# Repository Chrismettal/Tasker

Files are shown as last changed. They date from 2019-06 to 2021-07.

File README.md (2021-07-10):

Tasker_v0.3 Logo

# MOVING TO GITLAB

This project has been moved to Gitlab and will NOT be updated here anymore!

https://gitlab.com/Chrismettal/Tasker

Reworked version of Reminder with Google Calendar providing the same functionality as the original design, but providing an etched PCB making the build much cleaner and easier while providing a bit more documentation.
The PCB mostly uses SMD parts and includes everything to enable USB-upload just like a Wemos D1 mini for example.

Please check out Andreas' video of his original design:
https://www.youtube.com/watch?v=sm1-l5-z3ag

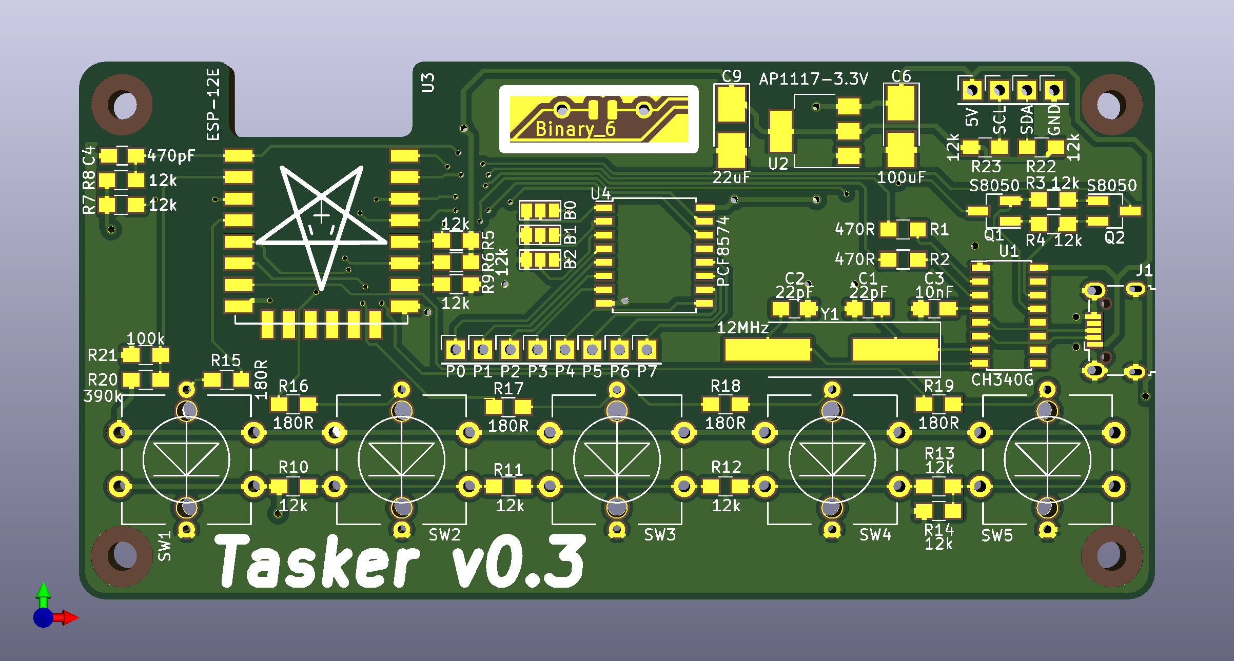
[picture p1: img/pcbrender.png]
Tasker_v0.3 PCB


Based on the original analog version to use 5 Buttons and 5 LEDs with available GPIO.

A PCF8574 port expander is routed over i2c on the PCB but currently not implemented in source code. Does not need to be placed for the rest to function. Could be implemented for further external triggers to set/reset automated functions.

# Buying

The PCB is now stocked on my Tindie store!



# Build Notes

Upload the gerber files made to your favourite PCB shop (or write me, i have spares).
The micro usb footprint is the "Wuerth Micro-B #629105150521" type, but a lot of chinese noname ones fit. If you can't get "the real thing" just look for a pack of various sizes. Some will fit.
__Flux it up!__
Start by placing the usb jack first as the CH340G will block your access a bit should you mess up the fine pins of the jack. Then place all the resistors, capacitos, transistors, then the bigger ICs and the crystal.
Only after all SMD parts are placed put in the buttons.

__Double check LED, C6 and C9 polarity!__

- C6 and C9 are tantalum caps that explode violently when you get their polarity wrong. The stripe (positive) should point to the C6/C9 writing on the PCB.
- R22 and R23 are optional I2C pullups, should you use something like an LCD over the I2C bus.
- Should you plan to upload code to the ESP before placing it, you could leave out U1, Q1, Q2, C1, C2, R1, R2, R3, R4, Y1.
- It does not matter if you power the device via USB or directly wire in 5 V to the pin header.
- U4 is optional. Should you place it you also have to place R22 and R23 and set an adress via B0, B1, B2.
- P0 - P7 are the in/outputs of U4.
- That cheap, chinese Arduino clone in your drawer is a good source for the CH340G that you forgot to order.
- You could also just order the bigger version of a NodeMCU and steal the ESP, AMS1117-3.3 ,CH340G and S8050s from that if you own a hot air rework station.
- If you are unhappy with the brightness of the LEDs you could change the values of R15 - R19. 

# Case

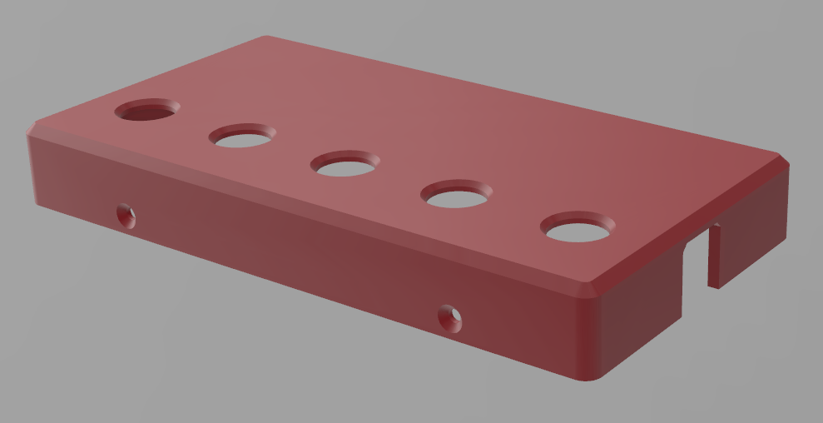
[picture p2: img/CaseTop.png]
CaseTop

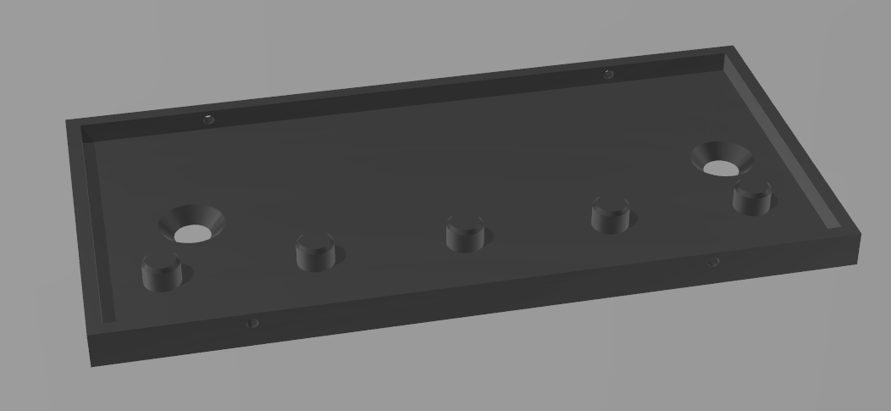
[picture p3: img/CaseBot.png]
CaseBot

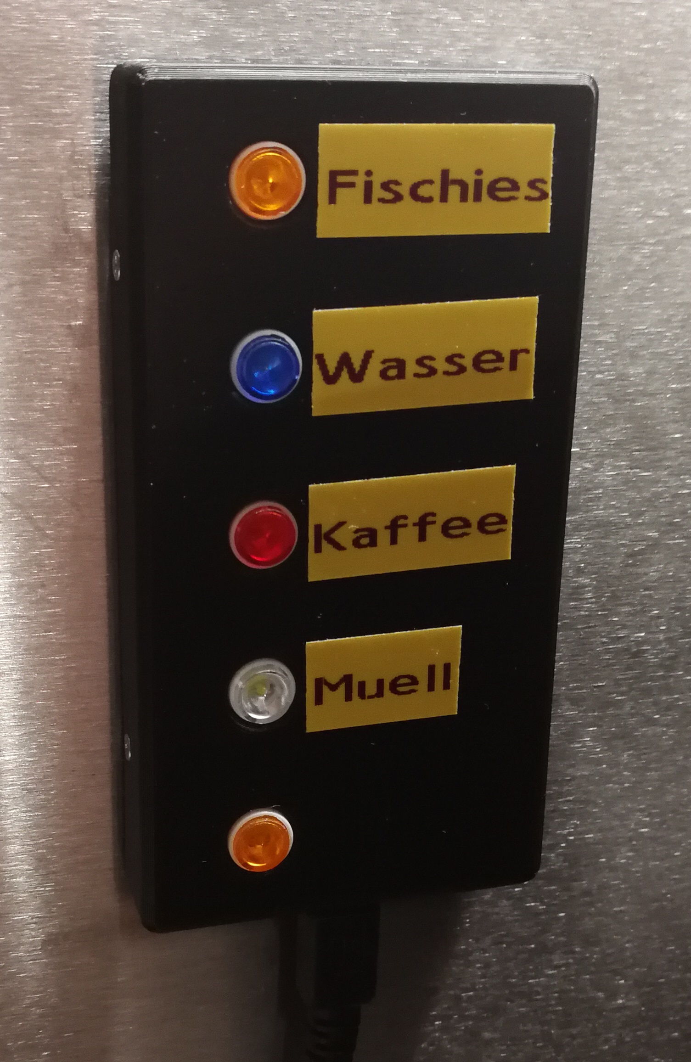
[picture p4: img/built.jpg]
Built


The case is 3d printed just like the master, but a lot thinner and i hope more elegant. Any material is fine, no supports needed if you lay the top flat face down.
I use course M2*8 screws to mount the PCB in the upper part as well as screwing the upper part to the lower part, which gets mounted to a wall first.
Like the master you can just put stickers on the case next to the buttons or emboss your tasks into the top part STL.

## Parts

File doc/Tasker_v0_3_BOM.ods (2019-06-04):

Designator | Package | pcs | Value
Resistor
R1,R2 | R_0805_HandSoldering | 2 | 470R
R3,R4,R5,R6,R7,R8,R9,R10,R11,R12,R13,R14,R22,R23 | R_0805_HandSoldering | 15 | 12k
R15,R16,R17,R18,R19 | R_0805_HandSoldering | 5 | 180R
R20 | R_0805_HandSoldering | 1 | 390k
R21 | R_0805_HandSoldering | 1 | 100k
Capacitor
C1,C2 | C_0805_HandSoldering | 2 | 22pF
C3 | C_0805_HandSoldering | 1 | 10nF
C4 | C_0805_HandSoldering | 1 | 470pF
C6 | CP_Tantalum_Case-B_EIA-3528-21 | 1 | 100uF
C9 | CP_Tantalum_Case-B_EIA-3528-21 | 1 | 22uF
IC
U1 | SOIC-16_3.9x9.9mm_Pitch1.27mm | 1 | CH340G
U2 | SOT-223-3_TabPin2 | 1 | AMS1117-3.3V
U3 | ESP-12E_SMD | 1 | ESP-12E
U4 | SOIC-16W_7.5x10.3mm_Pitch1.27mm | 1 | PCF8574
Transistor
Q1,Q2 | SOT-23_Handsoldering | 2 | S8050
Crystal
Y1 | Crystal_SMD_HC49-SD_HandSoldering | 1 | 12MHz
Connectors
J1 | USB_Micro-B_Wuerth-629105150521 | 1 | USB_OTG
J2 | Socket_Strip_Straight_1x01_Pitch2.54mm | 1 | 5V
J3 | Socket_Strip_Straight_1x01_Pitch2.54mm | 1 | SCL
J4 | Socket_Strip_Straight_1x01_Pitch2.54mm | 1 | SDA
J5 | Socket_Strip_Straight_1x01_Pitch2.54mm | 1 | GND
J6 | Socket_Strip_Straight_1x01_Pitch2.54mm | 1 | P0
J7 | Socket_Strip_Straight_1x01_Pitch2.54mm | 1 | P1
J8 | Socket_Strip_Straight_1x01_Pitch2.54mm | 1 | P2
J9 | Socket_Strip_Straight_1x01_Pitch2.54mm | 1 | P3
J10 | Socket_Strip_Straight_1x01_Pitch2.54mm | 1 | P4
J11 | Socket_Strip_Straight_1x01_Pitch2.54mm | 1 | P5
J12 | Socket_Strip_Straight_1x01_Pitch2.54mm | 1 | P6
J13 | Socket_Strip_Straight_1x01_Pitch2.54mm | 1 | P7
Pushbuttons
SW1,SW2,SW3,SW4,SW5 | 12mm_LED_pushbutton | 5 | SW_Push_LED

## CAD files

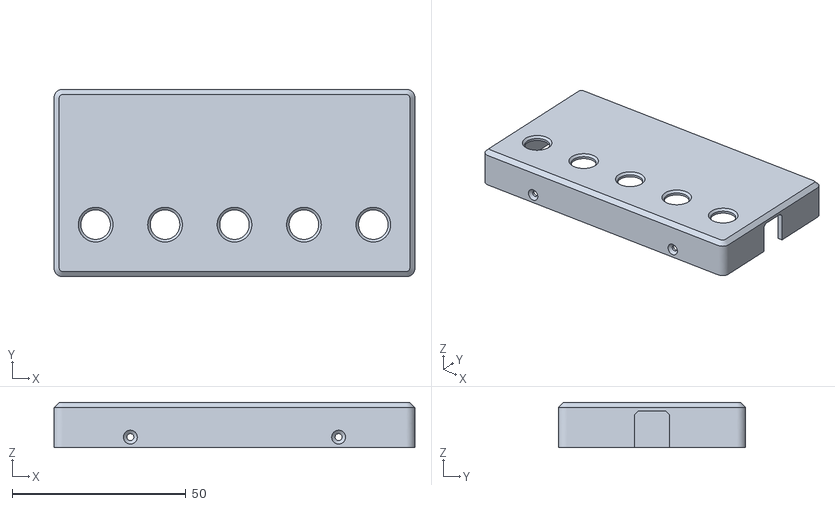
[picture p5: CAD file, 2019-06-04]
3D/Tasker_v0_3_top.stl
104.0 x 54.0 x 13.0

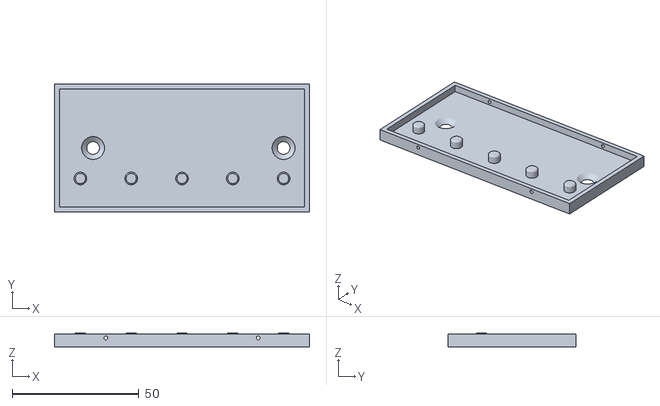
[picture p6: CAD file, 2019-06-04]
3D/Tasker_v0_3_bottom.stl
100.4 x 50.4 x 5.40

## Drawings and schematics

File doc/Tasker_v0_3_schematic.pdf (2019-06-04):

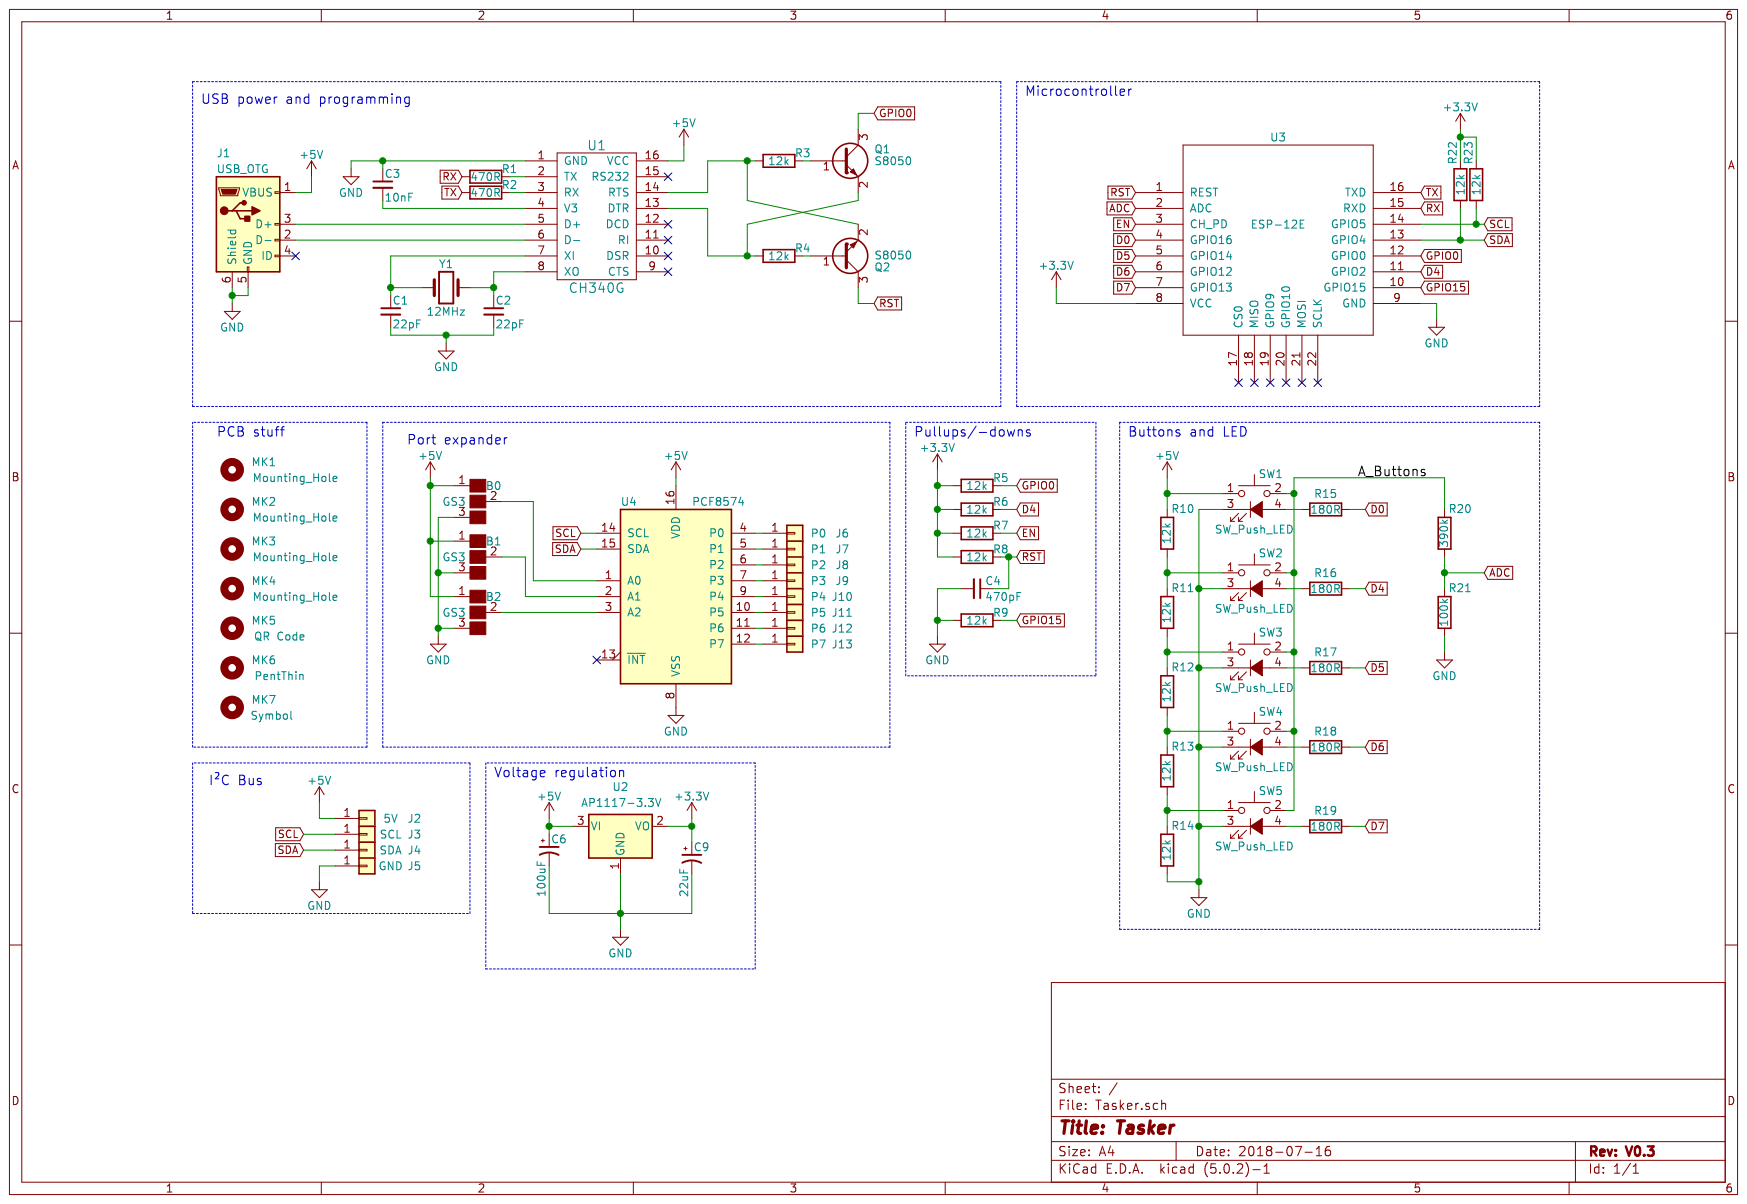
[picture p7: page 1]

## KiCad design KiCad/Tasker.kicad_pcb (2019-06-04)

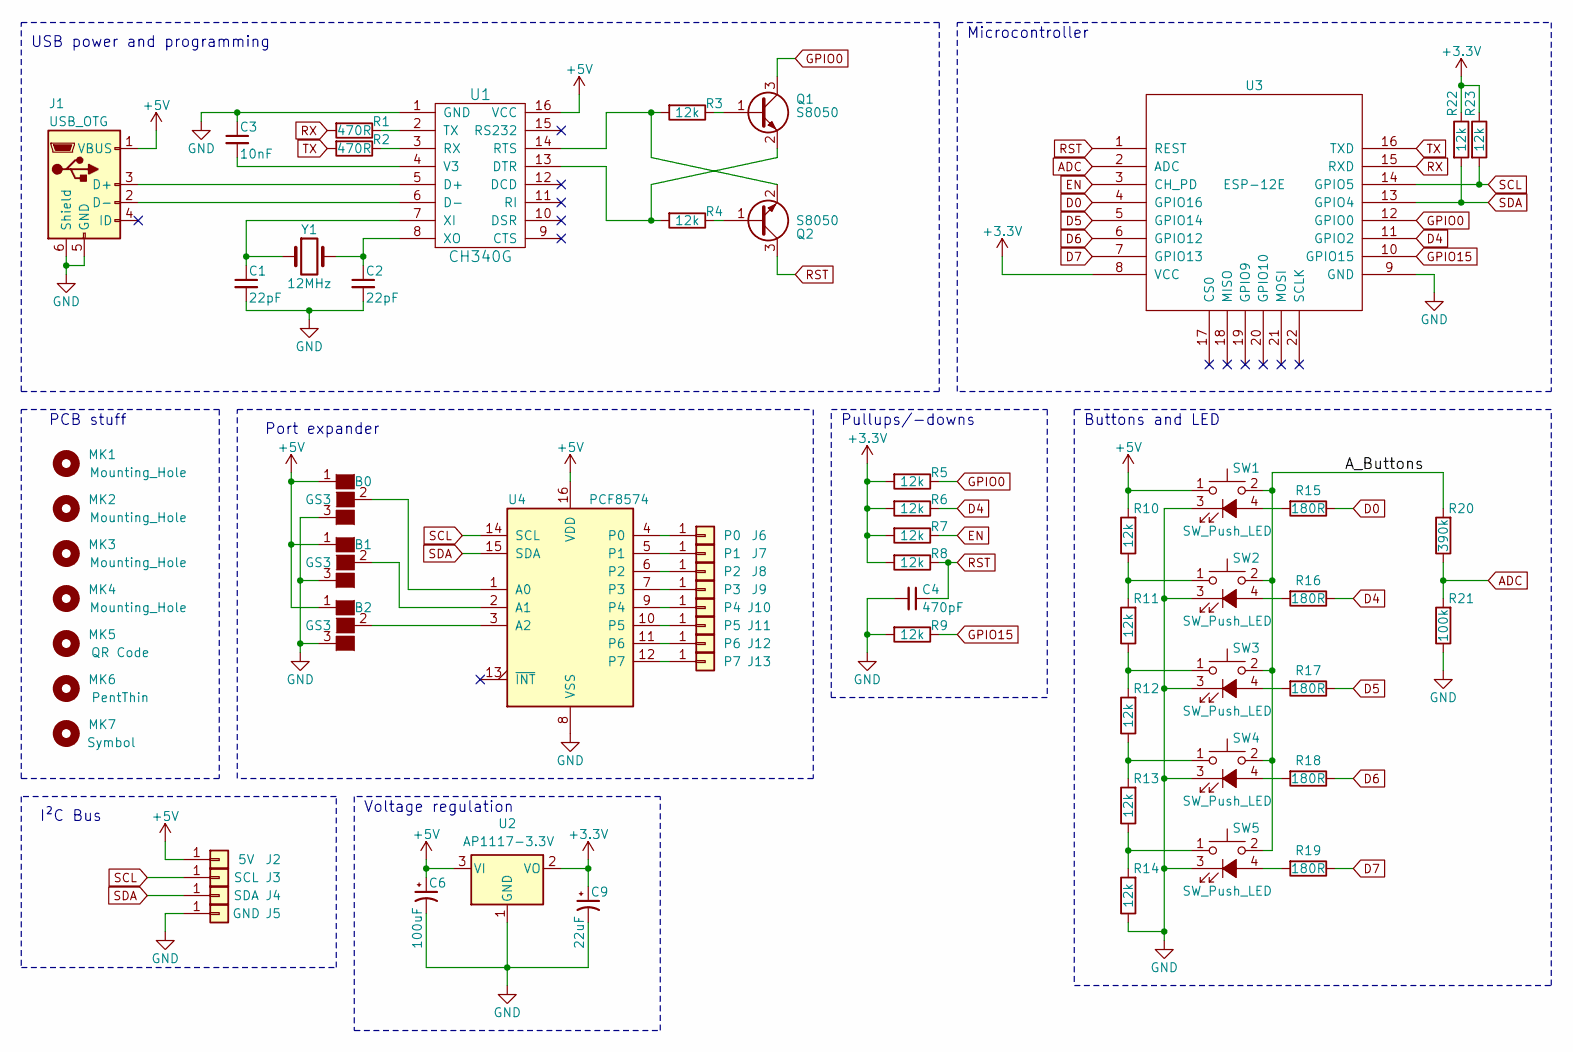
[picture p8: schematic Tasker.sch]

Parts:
B0, B1, B2: GS3
C1, C2: 22pF; C_0805_HandSoldering
C3: 10nF; C_0805_HandSoldering
C4: 470pF; C_0805_HandSoldering
C6: 100uF; CP_Tantalum_Case-B_EIA-3528-21_Hand
C9: 22uF; CP_Tantalum_Case-B_EIA-3528-21_Hand
J1: USB_OTG; USB_Micro-B_Wuerth-629105150521
J2: 5V; Socket_Strip_Straight_1x01_Pitch2.54mm
J3: SCL; Socket_Strip_Straight_1x01_Pitch2.54mm
J4: SDA; Socket_Strip_Straight_1x01_Pitch2.54mm
J5: GND; Socket_Strip_Straight_1x01_Pitch2.54mm
J6: P0; Socket_Strip_Straight_1x01_Pitch2.54mm
J7: P1; Socket_Strip_Straight_1x01_Pitch2.54mm
J8: P2; Socket_Strip_Straight_1x01_Pitch2.54mm
J9: P3; Socket_Strip_Straight_1x01_Pitch2.54mm
J10: P4; Socket_Strip_Straight_1x01_Pitch2.54mm
J11: P5; Socket_Strip_Straight_1x01_Pitch2.54mm
J12: P6; Socket_Strip_Straight_1x01_Pitch2.54mm
J13: P7; Socket_Strip_Straight_1x01_Pitch2.54mm
MK1, MK2, MK3, MK4: Mounting_Hole; EigenesMountingHole_2.7mm_M2.5
MK5: QR Code; QR_Tasker
MK6: PentThin
MK7: Symbol; Dickbutt
Q1, Q2: S8050; SOT-23_Handsoldering
R1, R2: 470R; R_0805_HandSoldering
R3, R4, R5, R6, R7, R8, R9, R10, R11, R12, R13, R14, R22, R23: 12k; R_0805_HandSoldering
R15, R16, R17, R18, R19: 180R; R_0805_HandSoldering
R20: 390k; R_0805_HandSoldering
R21: 100k; R_0805_HandSoldering
SW1, SW2, SW3, SW4, SW5: SW_Push_LED; 12mm_LED_pushbutton
U1: CH340G; SOIC-16_3.9x9.9mm_Pitch1.27mm
U2: AP1117-3.3V; SOT-223-3_TabPin2
U3: ESP-12E; ESP-12E_SMD
U4: PCF8574; SOIC-16W_7.5x10.3mm_Pitch1.27mm
Y1: 12MHz; Crystal_SMD_HC49-SD_HandSoldering

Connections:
+3V3: C9.1, R5.2, R6.2, R7.2, R8.2, R22.1, R23.1, U2.2 (VO), U3.8 (VCC)
+5V: B0.1 (G1), B1.1 (G1), B2.1 (G1), C6.1, J1.1 (VBUS), J2.1, R10.2, SW1.1, U1.16 (VCC), U2.3 (VI), U4.16 (VDD)
/A_Buttons: R20.2, SW1.2, SW2.2, SW3.2, SW4.2, SW5.2
ADC: R20.1, R21.2, U3.2 (ADC)
D0: R15.1, U3.4 (GPIO16)
D4: R6.1, R16.1, U3.11 (GPIO2)
D5: R17.1, U3.5 (GPIO14)
D6: R18.1, U3.6 (GPIO12)
D7: R19.1, U3.7 (GPIO13)
EN: R7.1, U3.3 (CH_PD)
GND: B0.3 (G3), B1.3 (G3), B2.3 (G3), C1.2, C2.2, C3.1, C4.2, C6.2, C9.2, J1.5 (GND), J1.6 (Shield), J5.1, R9.2, R14.1, R21.1, SW1.3 (K), SW2.3 (K), SW3.3 (K), SW4.3 (K), SW5.3 (K), U1.1 (GND), U2.1 (GND), U3.9 (GND), U4.8 (VSS)
GPIO0: Q1.3 (C), R5.1, U3.12 (GPIO0)
GPIO15: R9.1, U3.10 (GPIO15)
unnamed: B0.2 (G2), U4.1 (A0)
unnamed: B1.2 (G2), U4.2 (A1)
unnamed: B2.2 (G2), U4.3 (A2)
unnamed: C1.1, U1.7 (XI), Y1.1
unnamed: C2.1, U1.8 (XO), Y1.2
unnamed: C3.2, U1.4 (V3)
unnamed: J1.2 (D-), U1.6 (D-)
unnamed: J1.3 (D+), U1.5 (D+)
unnamed: J6.1, U4.4 (P0)
unnamed: J7.1, U4.5 (P1)
unnamed: J8.1, U4.6 (P2)
unnamed: J9.1, U4.7 (P3)
unnamed: J10.1, U4.9 (P4)
unnamed: J11.1, U4.10 (P5)
unnamed: J12.1, U4.11 (P6)
unnamed: J13.1, U4.12 (P7)
unnamed: Q1.1 (B), R3.1
unnamed: Q1.2 (E), R4.2, U1.13 (DTR)
unnamed: Q2.1 (B), R4.1
unnamed: Q2.2 (E), R3.2, U1.14 (RTS)
unnamed: R1.1, U1.2 (TX)
unnamed: R2.1, U1.3 (RX)
unnamed: R10.1, R11.2, SW2.1
unnamed: R11.1, R12.2, SW3.1
unnamed: R12.1, R13.2, SW4.1
unnamed: R13.1, R14.2, SW5.1
unnamed: R15.2, SW1.4 (A)
unnamed: R16.2, SW2.4 (A)
unnamed: R17.2, SW3.4 (A)
unnamed: R18.2, SW4.4 (A)
unnamed: R19.2, SW5.4 (A)
RST: C4.1, Q2.3 (C), R8.1, U3.1 (REST)
RX: R1.2, U3.15 (RXD)
SCL: J3.1, R23.2, U3.14 (GPIO5), U4.14 (SCL)
SDA: J4.1, R22.2, U3.13 (GPIO4), U4.15 (SDA)
TX: R2.2, U3.16 (TXD)

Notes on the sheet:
USB power and programming
Pullups/-downs
Voltage regulation
Microcontroller
Buttons and LED
PCB stuff
I²C Bus
Port expander

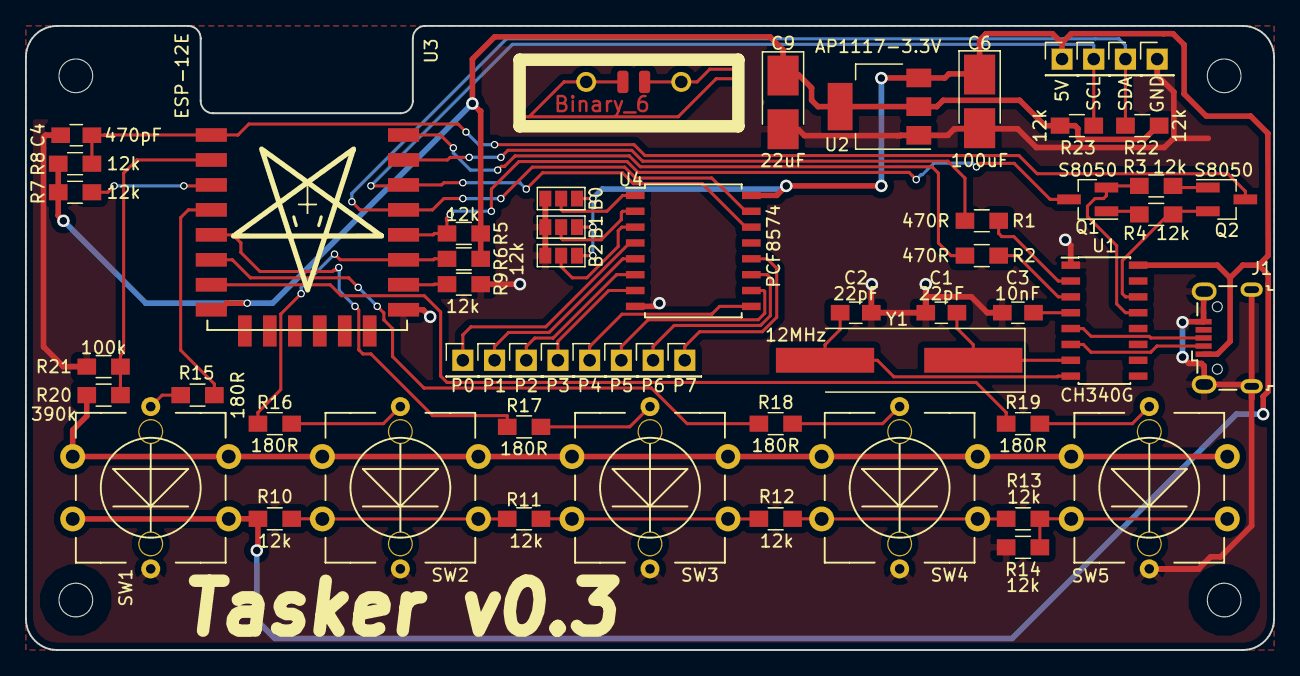
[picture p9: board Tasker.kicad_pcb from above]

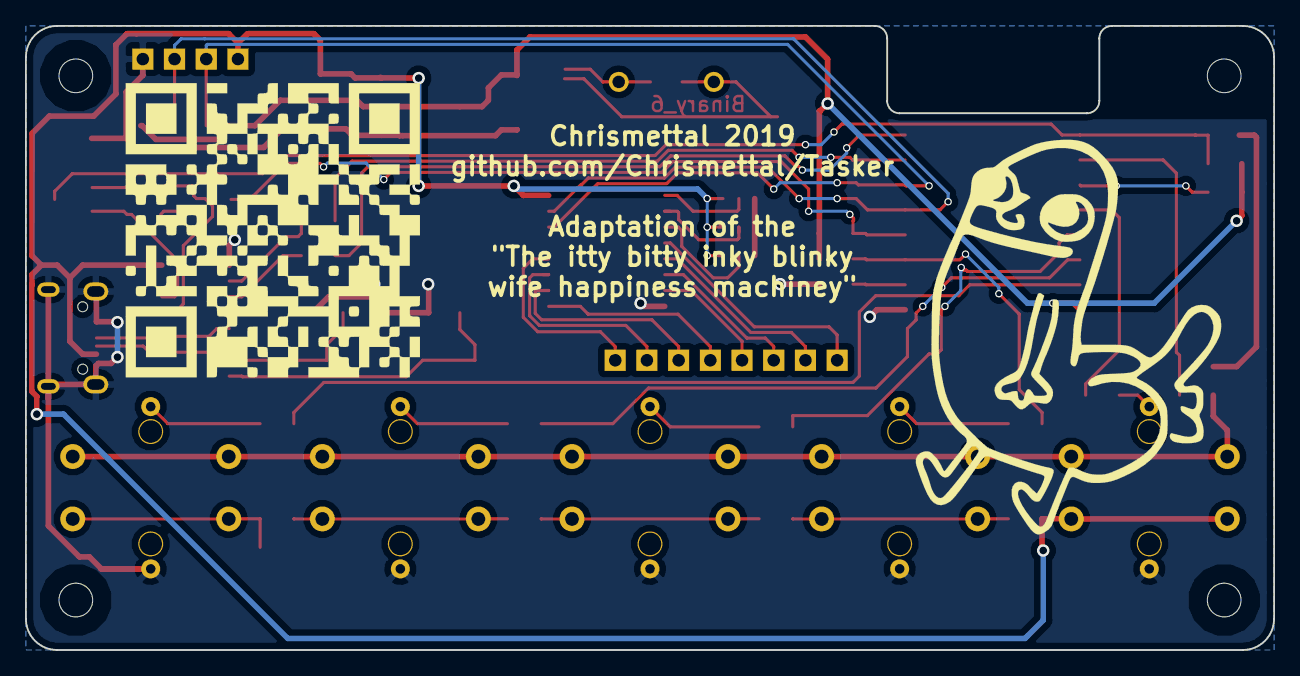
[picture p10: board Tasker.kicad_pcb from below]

Board: 2 copper layers, 100.0 x 50.0 mm, 65 parts (2 on the bottom side), 49 nets.

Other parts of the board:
H7: Symbol_Binary6; Binary_6_v0.1

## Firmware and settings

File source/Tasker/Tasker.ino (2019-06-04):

/*
Remixed version of "Itty bitty inky blinky wife happiness machiney" by Chrismettal, original design by Anreas Spiess.
Edited for use with etched PCB "Tasker v0.3"
PCB includes PCF8574 port expander (because there was space left) over i2c but is currently not used in sourcecode

Documentation: github.com/chrismettal/Tasker



Original copyright information from master still applies:

  Copyright <2018> <Andreas Spiess>

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
  The above copyright notice and this permission notice shall be included in all copies or substantial portions of the Software.

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
  Based on:

    Google Calendar Integration ESP8266
    Created by Daniel Willi, 2016

    Based on the WifiClientSecure example by
    Ivan Grokhotkov

/end original copyright from master

*/

// from LarryD, Arduino forum
#define DEBUG   //If you comment this line, the DPRINT & DPRINTLN lines are defined as blank.
#ifdef DEBUG    //Macros are usually in all capital letters.
#define DPRINT(...)    Serial.print(__VA_ARGS__)     //DPRINT is a macro, debug print
#define DPRINTLN(...)  Serial.println(__VA_ARGS__)   //DPRINTLN is a macro, debug print with new line
#else
#define DPRINT(...)     //now defines a blank line
#define DPRINTLN(...)   //now defines a blank line
#endif

#include <ESP8266WiFi.h>
#include <Ticker.h>
#include "HTTPSRedirect.h"

Ticker blinker;

//Connection Settings
const char* host = "script.google.com";
const char* googleRedirHost = "script.googleusercontent.com";
const int httpsPort = 443;

unsigned long entryCalender, entryPrintStatus, entrySwitchPressed;
String url;

unsigned long intEntry;


#define UPDATETIME 20000

//Network credentials
const char* ssid = "MyWiFi"; //replace with you ssid
const char* password = "MyPassword"; //replace with your password
//Google Script ID
const char *GScriptIdRead = "MyReadScriptId"; //replace with you gscript id for reading the calendar
const char *GScriptIdWrite = "MyWriteScriptId"; //replace with you gscript id for writing the calendar

//For the Rev_0.3 PCB only 5 events are possible
#define NBR_EVENTS 5

/*These Arrays corrospond with the buttons/tasks that can be displayed. The name of the event has to be
  the same as the calender event. The order of buttons is:
Button:   |  SW5  |  SW4  |  SW3  |  SW2  |  SW1  |
Pin:      |  D7   |  D6   |  D5   |  D4   |  D0   |
Array pos:|  [1]  |  [2]  |  [3]  |  [4]  |  [5]  | */
String  possibleEvents[NBR_EVENTS] = {"unused", "Trash", "Clean Coffeemaker", "Waterchange",  "Feed Fish"};
byte  LEDpins[NBR_EVENTS]    = {D7, D6, D5, D4, D0};
bool switchPressed[NBR_EVENTS];
unsigned long switchOff = 0;

//Enumerator for the possible states of every task
enum taskStatus {
  none,
  due,
  done
};

taskStatus taskStatus[NBR_EVENTS];

String calendarData = "";
bool calenderUpToDate;

//Connect to wifi
void connectToWifi() {
  Serial.println();
  Serial.print("Connecting to wifi: ");
  Serial.println(ssid);

  WiFi.begin(ssid, password);
  while (WiFi.status() != WL_CONNECTED) {
    delay(500);
    Serial.print(".");
  }
  Serial.println("");
  Serial.print("WiFi connected ");
  Serial.print("IP address: ");
  Serial.println(WiFi.localIP());

  // Use HTTPSRedirect class to create TLS connection
  HTTPSRedirect client(httpsPort);

  Serial.print("Connecting to ");
  Serial.println(host);
  bool flag = false;
  for (int i = 0; i < 5; i++) {
    int retval = client.connect(host, httpsPort);
    if (retval == 1) {
      flag = true;
      break;
    }
    else  Serial.println("Connection failed. Retrying...");
    if (!flag) {
      Serial.print("Could not connect to server: ");
      Serial.println(host);
      Serial.println("Exiting...");
      ESP.reset();
    }
  }
  Serial.println("Connected to Google");
}

void printStatus() {
  for (int i = 0; i < NBR_EVENTS; i++) {
    Serial.print("Task ");
    Serial.print(i);
    Serial.print(" Status ");
    Serial.println(taskStatus[i]);
  }
  Serial.println("----------");
}

void getCalendar() {
  Serial.println("Start Request");
  HTTPSRedirect client(httpsPort);
  unsigned long getCalenderEntry = millis();
  while (!client.connected() && millis() < getCalenderEntry + 8000) {
    Serial.print(".");
    client.connect(host, httpsPort);
  }

  //Fetch Google Calendar events
  url = String("/macros/s/") + GScriptIdRead + "/exec";
  calendarData = client.getData(url, host, googleRedirHost);
  Serial.print("Calendar Data---> ");
  Serial.println(calendarData);
  calenderUpToDate = true;
  yield();
}

void createEvent(String title) {
  Serial.println("Start Write Request");
  HTTPSRedirect client(httpsPort);
  if (!client.connected()) client.connect(host, httpsPort);
  // Create event on Google Calendar
  url = String("/macros/s/") + GScriptIdWrite + "/exec" + "?title=" + title;
  client.getData(url, host, googleRedirHost);
  Serial.println(url);
  Serial.println("Write Event created ");
  calenderUpToDate = false;
}

void manageStatus() {
  for (int i = 0; i < NBR_EVENTS; i++) {
    switch (taskStatus[i]) {
      case none:
        if (switchPressed[i]) {
          digitalWrite(LEDpins[i], HIGH);
          while (!calenderUpToDate) getCalendar();
          if (!eventHere(i)) createEvent(possibleEvents[i]);
          Serial.print(i);
          Serial.println(" 0-->1");
          //getCalendar();
          taskStatus[i] = due;
        } else {
          if (eventHere(i)) {
            digitalWrite(LEDpins[i], HIGH);
            Serial.print(i);
            Serial.println(" 0-->1");
            taskStatus[i] = due;
          }
        }
        break;
      case due:
        if (switchPressed[i]) {
          digitalWrite(LEDpins[i], LOW);
          Serial.print(i);
          Serial.println(" 1-->2");
          taskStatus[i] = done;
        }
        break;
      case done:
        if (calenderUpToDate && !eventHere(i)) {
          digitalWrite(LEDpins[i], LOW);
          Serial.print(i);
          Serial.println(" 2-->0");
          taskStatus[i] = none;
        }
        break;
      default:
        break;
    }
    switchPressed[i] = false;
  }
  yield();
}

bool eventHere(int task) {
  if (calendarData.indexOf(possibleEvents[task], 0) >= 0 ) {
        //Serial.print("Task found ");
        //Serial.println(task);
    return true;
  } else {
       //Serial.print("Task not found ");
       //Serial.println(task);
    return false;
  }
}

void handleInterrupt() {
  //don't know if intEntry is even useful for anything now
  intEntry = millis();
  //measure the voltage on the analog pin and calculate which button was pressed
  int reading = analogRead(A0);
  //hi needs to be a float here because it is the result of a floating point calculation.
  //will be rounded down to an integer in the next step
  float hi = (reading / (1024.0 / NBR_EVENTS) - 0.5);

  //if some button was pressed..
  if (hi >= 0) {
    //and if no button was pressed for the last 10 ticker cycles
    if (switchOff > 10) {
      //get the number of the pressed button and set the corrosponding variable
      int button = (int)hi;
      switchPressed[button] = true;
    }
    //always reset the "no button pressed" duration during each press
    switchOff = 0;
  }
  //if no button was pressed count up switchOff
  else switchOff++;
}

void setup() {
  //start serial communication
  Serial.begin(19200);
  //attach the interrupt routine to fire every 50ms
  blinker.attach_ms(50, handleInterrupt);
  //start wifi connection
  connectToWifi();
  //reset all LEDs, tasks and buttons
  for (int i = 0; i < NBR_EVENTS; i++) {
    pinMode(LEDpins[i], OUTPUT);
    taskStatus[i] = none;
    switchPressed[i] = false;
  }
  //initial calendar update
  //every calendar update saves the time it was updated for cyclic updating
  getCalendar();
  entryCalender = millis();
}


void loop() {
  //Update the calendar data every "updatetime" duration
  if (millis() > entryCalender + UPDATETIME) {
    getCalendar();
    entryCalender = millis();
  }
  manageStatus();
  if (millis() > entryPrintStatus + 5000) {
    printStatus();
    entryPrintStatus = millis();
  }
}
